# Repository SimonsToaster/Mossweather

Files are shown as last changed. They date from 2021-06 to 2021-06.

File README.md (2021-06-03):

# Mossweather
Code and STL files for a weather station tracking weather data at moss sites using an arduino mega 2560.

This is a personal project aimed at creating a weather station used to record weather data at sites where bryophytes naturally grow. 
In its final form it should be able to track temperature of soil, at ground level, in the air, humidity of soil, at ground level and in the air, pressure, upwards and downwards radiation, precipitation and wind velocity. To correlate weather data with growth a camera is used to make pictures of the site. Besides high percise measurements long endurance is a key feature.

Hardware used is an Arduino Mega 2560 and compatible breakout boards.

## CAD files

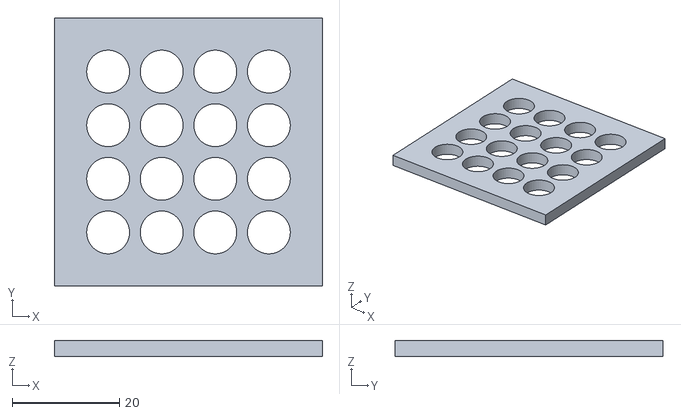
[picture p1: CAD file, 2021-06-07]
.stl files/Temperature housing/Temp_top_1.stl
50.0 x 50.0 x 3.00

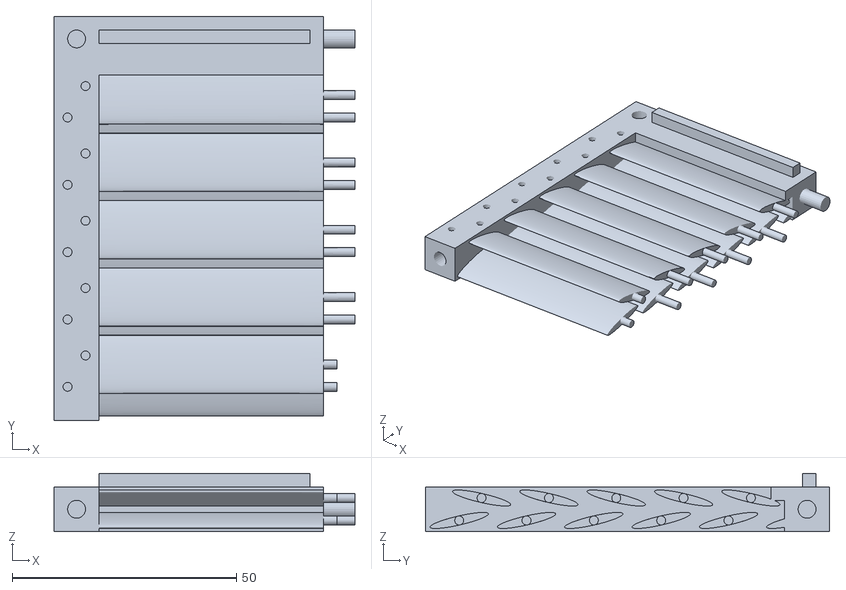
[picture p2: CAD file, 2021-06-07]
.stl files/Temperature housing/Temp_side.stl
67.0 x 90.0 x 13.0

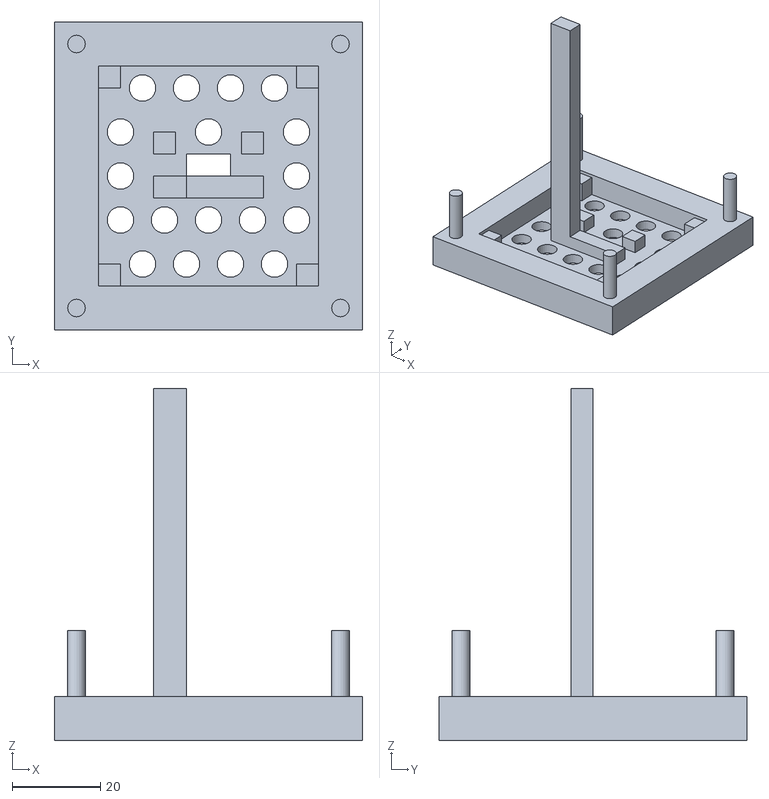
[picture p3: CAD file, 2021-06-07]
.stl files/Temperature housing/Temp_core.stl
70.0 x 70.0 x 80.0

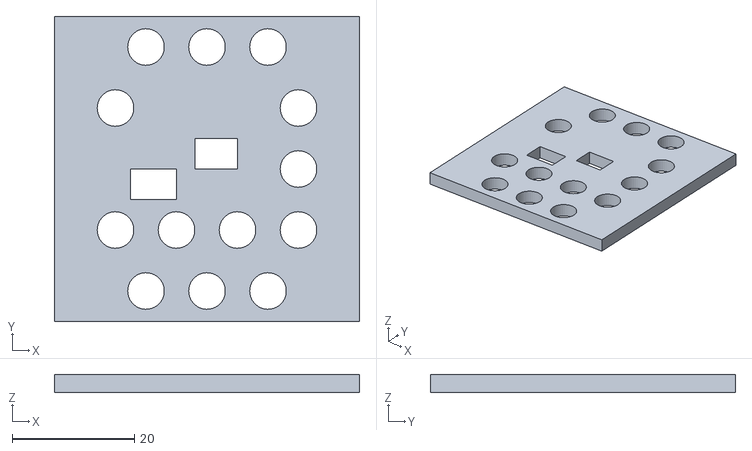
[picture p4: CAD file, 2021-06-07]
.stl files/Temperature housing/Temp_bottom.stl
50.0 x 50.0 x 3.00

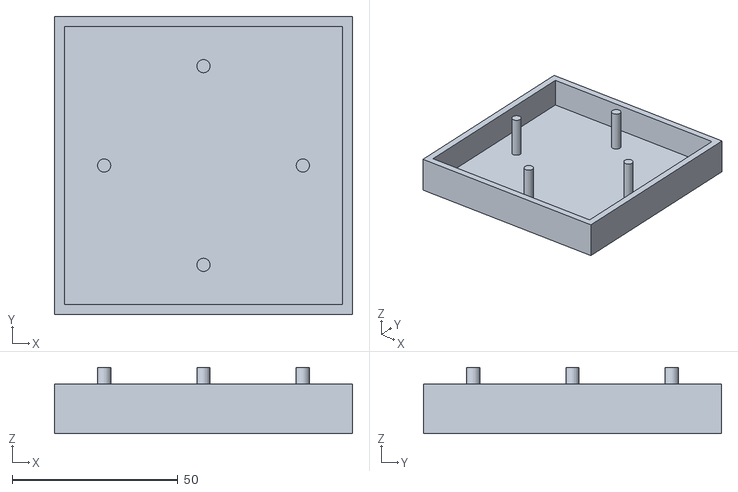
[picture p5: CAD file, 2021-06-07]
.stl files/Temperature housing/Temp_top_2.stl
90.0 x 90.0 x 20.0

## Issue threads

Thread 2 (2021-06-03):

Logging to file does not work

SimonsToaster, 2021-06-03:
The obtained measurement data is not written to the logfile. The cause for this behavior is currently unknown.

SimonsToaster, 2021-06-07:
Was fixed in last commit. Problem was that it was not specified which file "logfile" referred to. I think.

Closed 2021-06-07.

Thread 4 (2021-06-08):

Fixing ArduCam

SimonsToaster, 2021-06-08:
Pictures taken by ArduCam have a size of 0 kb.

SimonsToaster, 2021-06-08:
ArduCam now works and takes pictures which can be opened on PC.

Solution: Code used from example library was not compatible with the used hardware. As it turns out, the camera module is a Mini 5MP Plus (OV5642). Code for taking pictures was substituted from an example meant for this hardware, and it works now, even though I have no clue why.

Closed 2021-06-08.

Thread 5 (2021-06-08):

Implementing further power saving features

SimonsToaster, 2021-06-08:
Power economy can be increased by setting pins to a defined, state, disabling certain modules etc. Look around the net and implement easy methods.

SimonsToaster, 2021-06-08:
Three additional power saving measures were implemented.

1) All unused pins are now set to an INPUT and LOW state. Should save 1 mA or less.
2) when going to sleep the ADC is disabled, which should save 0,35 mA.
3) By connecting the reset pin of the ATMEGA16U2 to a digital pin it can be continually reset when no longer needed, saving a couple of mA. Using a pin is perferably to a jumper since it was discovered that a continually reset chip deeds more energy than one reset after an initial power up. (https://forum.arduino.cc/t/mega-2560-power-saving-strom-sparen/249290/31)

While implementing it was found that the Arduino wouldn't wake up after being sent to sleep. Reason was a missing connection between the interrupt pin and the rtc.

Closed 2021-06-08.

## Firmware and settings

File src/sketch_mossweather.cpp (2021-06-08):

//-----------------------------------------------------------------------------------------------------------------------------------------------------------------
//Libraries

#include <avr/sleep.h>
#include <Adafruit_TSL2591.h>
#include <Adafruit_SHT31.h>
#include <Adafruit_BMP280.h>
#include <Adafruit_Sensor.h>
#include <RTClib.h>
#include <Wire.h>
#include <SPI.h>
#include <SD.h>
#include <ArduCAM.h>
#include "memorysaver.h"
extern "C"
{
#include "utility/twi.h"               // from Wire library, so we can do bus scanning
}

//-----------------------------------------------------------------------------------------------------------------------------------------------------------------
//Parameters - Control how often data is logged, sampling time, when to take a picture etc

const int log_intervall = 1;          //Time in minutes between logging. Needs to be lower than 240 (4 hours)
const int log_time = 10;               //Time in seconds for in which the measured quantity should be averaged. Every 10 seconds a measurement is taken. Needs to be between 10 and 300 (5 min)
const int pic_time = 12;               //Hour of the day when the picture is taken. Needs to be between 1 and 24. 
char filename[] = "LOGFILE.CSV";       //Name of the logfile

//-----------------------------------------------------------------------------------------------------------------------------------------------------------------
//Defined Pins

const int timerInterruptPin = 18;     //Pin at which the timer of the RTC will send its interrupt
const int SD_CS = 10;                 //I think this defines the pin for selecting the SD card for SPI
const int rst_rain = 2;               //Pins for resetting the rain and wind counters, need to be adjusted.
const int rst_wind = 4;
const int SPI_CS = 53;                //I think this defines the pinfor seleecting the camera for SPI
const int rst_16U2 = 19;               

const int unusedDigitalPins[] = { 1,      3,      5,  6,  7,  8,  9,  
                                     12, 13, 14, 15, 16, 17,        
                                     22, 23, 24, 25, 26, 27, 28, 29, 30,
                                 31, 32, 33, 34, 35, 36, 37, 38, 39, 40,
                                 41, 42, 43, 44, 45, 46, 47, 48, 49,  
                                      };
// 41 unused digital pins

//-----------------------------------------------------------------------------------------------------------------------------------------------------------------
//Settings for the clock, sensors etc.

RTC_PCF8523 rtc;

File logfile;

Adafruit_BMP280 bmp = Adafruit_BMP280();

bool enableHeater = false;
Adafruit_SHT31 sht31_grnd = Adafruit_SHT31();
Adafruit_SHT31 sht31_surf = Adafruit_SHT31();
Adafruit_SHT31 sht31_air = Adafruit_SHT31();

Adafruit_TSL2591 tsl_up = Adafruit_TSL2591(0x40);
Adafruit_TSL2591 tsl_dwn = Adafruit_TSL2591(0x50);

ArduCAM myCAM( OV5642, SPI_CS );

//-----------------------------------------------------------------------------------------------------------------------------------------------------------------
//Declared Functions  

//Interrupt service routine
volatile bool timer_set = false;

void wakeUp()
{
  sleep_disable(); 
  Serial.println("Sleep disabled");
  timer_set = false;
}

//Sleep routine
void Going_To_Sleep()
{
  attachInterrupt(digitalPinToInterrupt(timerInterruptPin), wakeUp, FALLING); 
  ADCSRA = 0;                                                                   // Disables ADC
  set_sleep_mode(SLEEP_MODE_PWR_DOWN);                                      
  sleep_enable(); 
  Serial.println ("Sleep enabled");                                                             
  sleep_cpu();                                                                
  Serial.println("woken up");
  detachInterrupt(digitalPinToInterrupt(timerInterruptPin));
}

//Math functions
long a_average(long array[])
{
  long sum_av = 0;
  for (int i_av = 0; i_av < 10; i_av++)
  {
    sum_av = sum_av + array[i_av];
  }
  long a_av = sum_av / 10;
  return a_av;
}

double a_std(long array[])
{
  long sum = 0;
  for (int i_std1 = 0; i_std1 < 10; i_std1++)
  {
    sum = sum + array[i_std1];
  }
  long std_av = sum / 10;

  long sum_sq = 0;
  for (int i_std2 = 0; i_std2 < 10; i_std2++)
  {
    sum_sq = sum_sq + (sq(array[i_std2] - std_av));
  }
  double std = sqrt(1/9.0 * sum_sq);
  return std;
}

//ArduCAM takes a picture and saves it to the SD card
void myCAMSaveToSDFile(ArduCAM myCAM)
{
  char str[8];
  byte buf[256];
  static int i = 0;
  static int k = 0;
  uint8_t temp = 0,temp_last=0;
  uint32_t length = 0;
  bool is_header = false;
  File outFile;

  myCAM.clear_bit(ARDUCHIP_GPIO, GPIO_PWDN_MASK);
  delay(1000);

  //Flush the FIFO
  myCAM.flush_fifo();
  //Clear the capture done flag
  myCAM.clear_fifo_flag();
  //Start capture
  myCAM.start_capture();
  Serial.println(F("start Capture"));
  while(!myCAM.get_bit(ARDUCHIP_TRIG , CAP_DONE_MASK));
  Serial.println(F("Capture Done."));  
  length = myCAM.read_fifo_length();
  Serial.print(F("The fifo length is :"));
  Serial.println(length, DEC);
  if (length >= MAX_FIFO_SIZE) //8M
  {
    Serial.println(F("Over size."));
    return ;
  }
  if (length == 0 ) //0 kb
  {
    Serial.println(F("Size is 0."));
    return ;
  }
  //Construct a file name
  k = k + 1;
  itoa(k, str, 10);
  strcat(str, ".jpg");
  //Open the new file
  outFile = SD.open(str, O_WRITE | O_CREAT | O_TRUNC);
  if(!outFile)
  {
    Serial.println(F("File open faild"));
    return;
  }
  myCAM.CS_LOW();
  myCAM.set_fifo_burst();
  while ( length-- )
  {
    temp_last = temp;
    temp =  SPI.transfer(0x00);
    //Read JPEG data from FIFO
    if ( (temp == 0xD9) && (temp_last == 0xFF) ) //If find the end ,break while,
   {
     buf[i++] = temp;  //save the last  0XD9     
      //Write the remain bytes in the buffer
     myCAM.CS_HIGH();
      outFile.write(buf, i);    
      //Close the file
      outFile.close();
     Serial.println(F("Image save OK."));
     is_header = false;
      i = 0;
   }  
   if (is_header == true)
   { 
     //Write image data to buffer if not full
     if (i < 256)
       buf[i++] = temp;
     else
      {
       //Write 256 bytes image data to file
        myCAM.CS_HIGH();
        outFile.write(buf, 256);
        i = 0;
        buf[i++] = temp;
        myCAM.CS_LOW();
        myCAM.set_fifo_burst();
     }        
    }
   else if ((temp == 0xD8) & (temp_last == 0xFF))
   {
     is_header = true;
      buf[i++] = temp_last;
     buf[i++] = temp;   
   } 
  }
  myCAM.set_bit(ARDUCHIP_GPIO, GPIO_PWDN_MASK);
  delay(1000);
}

//Allows easy swiching between ports of the multiplexer
#define TCAADDR 0x70
void tcaselect(uint8_t i)
{
  if (i > 7)
    return;
  Wire.beginTransmission(TCAADDR);
  Wire.write(1 << i);
  Wire.endTransmission();
}

//Configures radiation sensors
void configureSensor(void)
{
  tsl_up.setGain(TSL2591_GAIN_MED);                // You can change the gain on the fly, to adapt to brighter/dimmer light situations 1x gain (bright light), 25x gain, 428x gain
  tsl_up.setTiming(TSL2591_INTEGRATIONTIME_300MS); // Changing the integration time gives you a longer time over which to sense light longer timelines are slower, but are good in very low light situtations! Possible: 100, 200, ..., 600.
  tsl_dwn.setGain(TSL2591_GAIN_MED);
  tsl_dwn.setTiming(TSL2591_INTEGRATIONTIME_300MS);
}


//-----------------------------------------------------------------------------------------------------------------------------------------------------------------
//Setup function

void setup()
{

  //Initializing the RTC
  Serial.begin(921600);
  delay(100);

  if (!rtc.begin())
  {
    Serial.println("Couldn't find RTC");
    Serial.flush();
    abort();
  }

  if (!rtc.initialized() || rtc.lostPower())
  {
    Serial.println("RTC not initialized, setting time");
    rtc.adjust(DateTime(F(__DATE__), F(__TIME__)));       //When time needs to be set on a new device, or after a power loss, this line sets the RTC to the date & time this sketch was compiled
  }

  rtc.start();                                            //When the RTC was stopped and stays connected to the battery, it has to be restarted by clearing the STOP bit. Let's do this to ensure the RTC is running.

  pinMode(timerInterruptPin, INPUT_PULLUP);               //Set the pin attached to PCF8523 INT to be an input with pullup to HIGH. The PCF8523 interrupt pin will briefly pull it LOW at the end of a given countdown period, then it will be released to be pulled HIGH again.
  rtc.deconfigureAllTimers();
  rtc.enableCountdownTimer(PCF8523_FrequencyMinute, log_intervall);

  timer_set = true;

  //Initializing SD card
  SD.begin(SD_CS);

  if (!SD.begin(SD_CS)) {
    Serial.println("SD card not found");
    while (1);
  }
  
  Serial.println("card initialized");

  //creating logfile
  logfile = SD.open(filename, FILE_WRITE);

  if (!logfile)
  {
    Serial.println("couldnt create file");
  }

  Serial.print("Logging to: ");
  Serial.println(filename);

  logfile.println("Timestamp, Date/Time, Pressure[hPa], Std, TemperatureGround[°C], Std, TemperatureSurface[°C], Std, TemperatureAir[°C], Std, HumidityGround[%RH], Std, HumiditySurface[%RH], Std, HumidityAir[%RH], Std, RadiationUpwards[counts], Std, RadiationDownwards[counts], Std, PrecipitationLastHour[mm], WindVelocity,"); //Actually used header neds to be inserted
  Serial.println("Timestamp, Date/Time, Pressure[hPa], Std, TemperatureGround[°C], Std, TemperatureSurface[°C], Std, TemperatureAir[°C], Std, HumidityGround[%RH], Std, HumiditySurface[%RH], Std, HumidityAir[%RH], Std, RadiationUpwards[counts], Std, RadiationDownwards[counts], Std, PrecipitationLastHour[mm], WindVelocity,");

  logfile.close();

  //Scans the multiplexer to check if all Sensors are connected
  Wire.begin();
  Serial.println("\nTCAScanner ready!");

  for (uint8_t t = 0; t < 8; t++)
  {
    tcaselect(t);
    Serial.print("TCA Port #");
    Serial.println(t);

    for (uint8_t addr = 0; addr <= 127; addr++)
    {
      if (addr == TCAADDR || addr == 0x68 || addr == 0x3C)
        continue;

      uint8_t data;
      if (!twi_writeTo(addr, &data, 0, 1, 1))
      {
        Serial.print("Found I2C 0x");
        Serial.println(addr, HEX);
      }
    }
  }
  Serial.println("\ndone");

  //Initializing the pressure sensor
  tcaselect(0);
  Serial.println("tcaselect(0)");
  if (!bmp.begin())
  {
    Serial.println("Pressure sensor not detected on TCA line 0");
    while (1);
  }
  Serial.println("check passed");
  bmp.setSampling(Adafruit_BMP280::MODE_FORCED, Adafruit_BMP280::SAMPLING_NONE, Adafruit_BMP280::SAMPLING_X16, Adafruit_BMP280::FILTER_X16, Adafruit_BMP280::STANDBY_MS_500);
    /* Operating Mode. _NORMAL, _FORCED, _SLEEP exist. Forced mode wakes sensor up, performs a measurement, then lets the sensor go back to sleep. Forced mode thus must be enabled before each measurement. Temp. oversampling set to _NONE since temperature isnt measured with this sensor. Pressure oversampling set to maximum to achieve lowest noise possible. Filtering. Set to max. Standby time. */
  Serial.println("BMP configured");

  //Initializing the Temperature and Humidity sensors
  tcaselect(1);
  Serial.println("tcaselect(1)");
  if (!sht31_grnd.begin())
  {
    Serial.println("Temperature/Humidity sensor not detected on TCA line 1");
    while (1);
  }
  Serial.println("check passed");

  tcaselect(2);
  Serial.println("tcaselect(2)");
  if (!sht31_surf.begin())
  {
    Serial.println("Temperature/Humidity sensor not detected on TCA line 2");
    while (1);
  }
  Serial.println("check passed");

  tcaselect(3);
    Serial.println("tcaselect(3)");
  if (!sht31_air.begin())
  {
    Serial.println("Temperature/Humidity sensor not detected on TCA line 3");
    while (1);
  }
  Serial.println("check passed");

  //Initializing the upward and downward radiation sensors
  tcaselect(4);
  Serial.println("tcaselect(4)");
  if (!tsl_up.begin())
  {
    Serial.println("Upwards radiation sensor not detected on TCA line 4");
    while (1);
  }
  Serial.println("check passed");
  configureSensor();
  Serial.println("tsl_up configured");

  tcaselect(5);
  Serial.println("tcaselect(5)");
  if (!tsl_dwn.begin())
  {
    Serial.println("Downwards radiation sensor not detected on TCA line 5");
    while (1);
  }
  Serial.println("check passed");
  configureSensor();
  Serial.println("tsl_down configured");

  //Activating counter for rain
  pinMode(rst_rain, INPUT);
  digitalWrite(rst_rain, HIGH);                           //How do pull ups behave when powerd down?

  //Activating counter for wind
  pinMode(rst_wind, INPUT);
  digitalWrite(rst_wind, HIGH);

  //Code for Arducam

  uint8_t vid, pid;
  uint8_t temp;
  Wire.begin();
  Serial.println(F("ArduCAM Start"));

  pinMode(SPI_CS, OUTPUT);
  digitalWrite(SPI_CS, HIGH);                             //set the CS as an output:
  SPI.begin();                                            // initialize SPI:
  myCAM.clear_bit(ARDUCHIP_GPIO, GPIO_PWDN_MASK);         //Gets camera out of sleep mode

  //Reset the CPLD
  myCAM.write_reg(0x07, 0x80);
  delay(100);
  myCAM.write_reg(0x07, 0x00);
  delay(100);

  while (1)
  {
    //Check if the ArduCAM SPI bus is OK
    myCAM.write_reg(ARDUCHIP_TEST1, 0x55);
    temp = myCAM.read_reg(ARDUCHIP_TEST1);

    if (temp != 0x55)
    {
      Serial.println(F("SPI interface Error!"));
      delay(1000);
      continue;
    }
    else
    {
      Serial.println(F("SPI interface OK."));
      break;
    }
  }
  //Initialize SD Card
  SD.begin(SD_CS);
  while (!SD.begin(SD_CS))
  {
    Serial.println(F("SD Card Error!"));                  //Is this code here really needed?
    delay(1000);
  }
  Serial.println(F("SD Card detected."));

  while (1)
  {
    //Check if the camera module type is OV5642
    myCAM.wrSensorReg16_8(0xff, 0x01);
    myCAM.rdSensorReg16_8(OV5642_CHIPID_HIGH, &vid);
    myCAM.rdSensorReg16_8(OV5642_CHIPID_LOW, &pid);
    if ((vid != 0x56) || (pid != 0x42))
    {
      Serial.println(F("Can't find OV5642 module!"));
      delay(1000);
      continue;
    }
    else
    {
      Serial.println(F("OV5642 detected."));
      break;
    }
  }

  myCAM.set_format(JPEG);
  myCAM.InitCAM();
  myCAM.write_reg(ARDUCHIP_TIM, VSYNC_LEVEL_MASK);      //VSYNC is active HIGH
  myCAM.OV5642_set_JPEG_size(OV5642_2592x1944);         //Resolution, possible OV5642_320x240 OV5642_640x480 OV5642_1024x768 OV5642_1280x960 OV5642_1600x1200 OV5642_2048x1536 OV5642_2592x1944 OV5642_1920x1080
  delay(1000);

  myCAM.set_bit(ARDUCHIP_GPIO, GPIO_PWDN_MASK);         //Sends camera back to sleep



  //Checks if entered logging parameters are valid

  if (log_intervall > 240 || log_intervall < 1)
  {
    Serial.println("Time between logging events needs to be more than 1 Minute and less than 240 Minutes");
    while(1);
  }
  Serial.println("Logging intervall valid");
  if (log_time < 10 || log_time > 300)
  {
    Serial.println("Logging averaging time needs to be above 10 seconds and below 300 seconds");
    while(1);
  }
  Serial.println("Measuring time valid");
  if (pic_time < 1 || pic_time > 24)
  {
    Serial.println("Time at which the picture will be taken needs to be between 1 and 24");
    while(1);
  }
  Serial.println("Picture time valid");
  Serial.println("Logging parameters valid");

  //Setting Pins to input and high to conserve power

  for(int i = 0; i < 41; i++)
  {
    pinMode(unusedDigitalPins[i], OUTPUT);
    digitalWrite(unusedDigitalPins[i], LOW);
    Serial.print("Disabled pin: ");
    Serial.println(unusedDigitalPins[i]);
  }
  
  // Resetting USB-Controller to conserve power - Commented out for development reasons
  /*
  pinMode(19, OUTPUT);
  digitalWrite(19, LOW);
  */
}

//-----------------------------------------------------------------------------------------------------------------------------------------------------------------
//Loop function
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

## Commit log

2021-06-07 Added .stl files for thermometer house
    All currently available .stl files, meaning exactly the ones of the thermometer housing, were added.
    [Temp_bottom.stl, Temp_core.stl, Temp_side.stl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]
2021-06-07 Updates
    Removed no longer needed math functions and measurement routine,
    Data is now logged with 4 decimal places.
    Tried to implement timestamp-naming of pictures, does not work as intended.
    [sketch_mossweather.cpp]
2021-06-08 Ongoing development - Camera and power saving
    Camera is now able to capture pictures
    Sleep mode now works, ADC can get disabled, USB-R323-Chip can be disabled and all unused pins are defined as low.
